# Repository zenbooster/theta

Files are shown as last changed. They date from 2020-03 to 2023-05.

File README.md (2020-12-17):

# "Theta" - EUC Project
Простой, как паровоз, брутальный как бронепоезд ;)

Самодельный корпус для моноколеса.

Watch the video (https://youtu.be/x_wpeCRDHl8)

Для рамы используется экструзионный профиль 2020 и 2040.
Надо сделать сужение кверху.

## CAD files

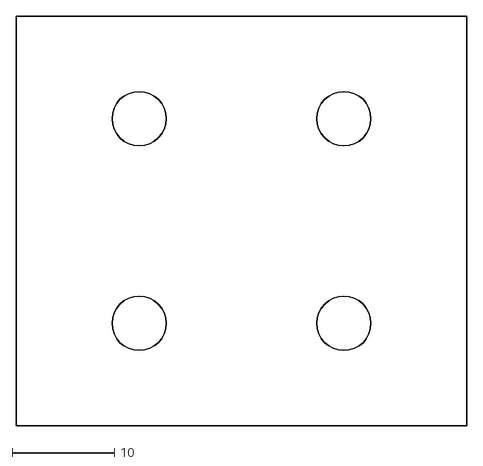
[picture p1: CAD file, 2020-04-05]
vector/dxf/4x_bcb.dxf
44.0 x 40.0

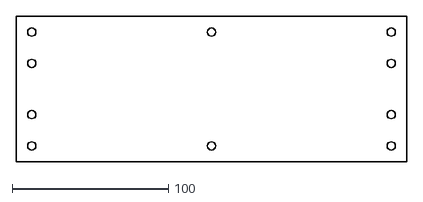
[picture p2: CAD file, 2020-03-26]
vector/ict.dxf
250.0 x 92.8

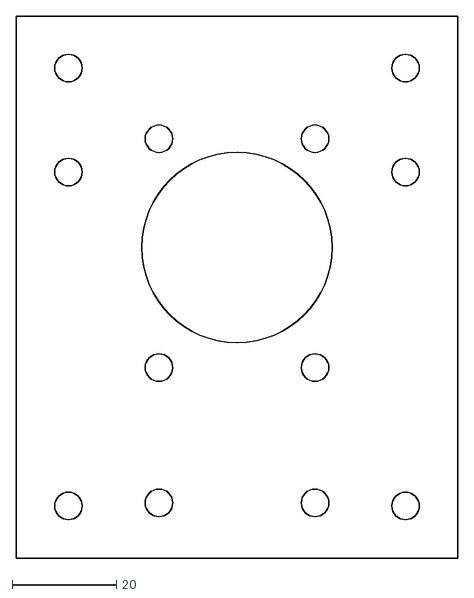
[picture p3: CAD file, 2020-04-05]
vector/dxf/2x_smc.dxf
84.8 x 104.2

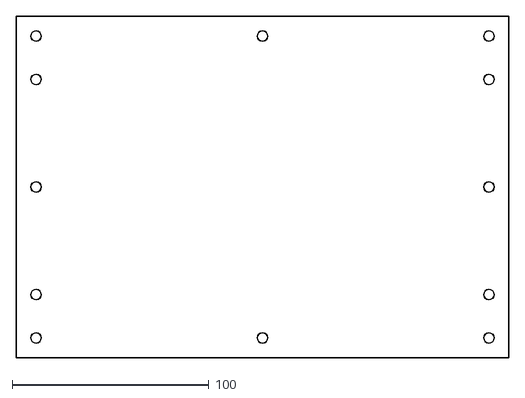
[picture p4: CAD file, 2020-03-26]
vector/icl.dxf
250.0 x 173.3

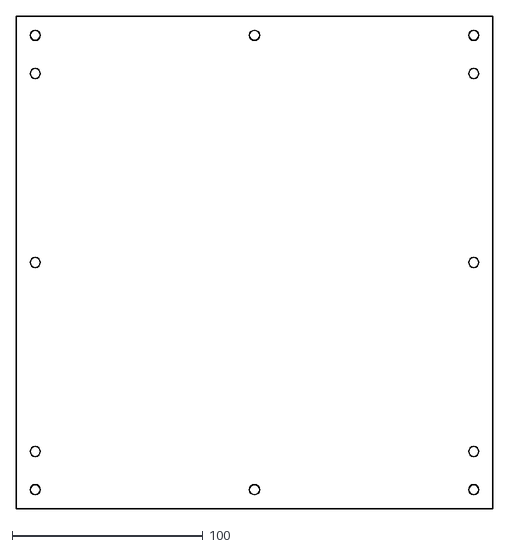
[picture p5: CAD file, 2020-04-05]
vector/dxf/2x_ocs.dxf
250.0 x 258.3

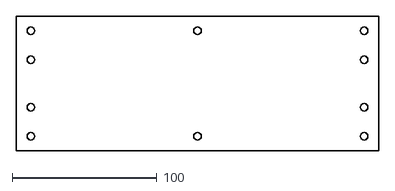
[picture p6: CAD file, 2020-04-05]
vector/dxf/1x_ict.dxf
250.0 x 92.8

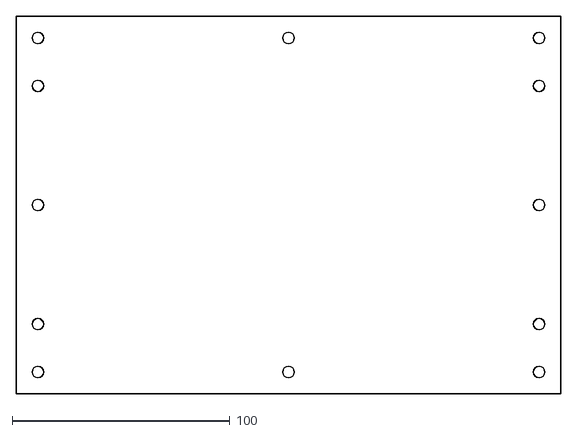
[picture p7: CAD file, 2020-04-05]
vector/dxf/1x_icl.dxf
250.0 x 173.3

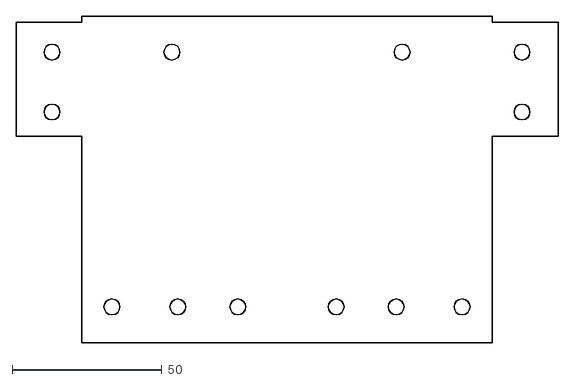
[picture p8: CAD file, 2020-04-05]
vector/dxf/2x_bct.dxf
180.8 x 109.0

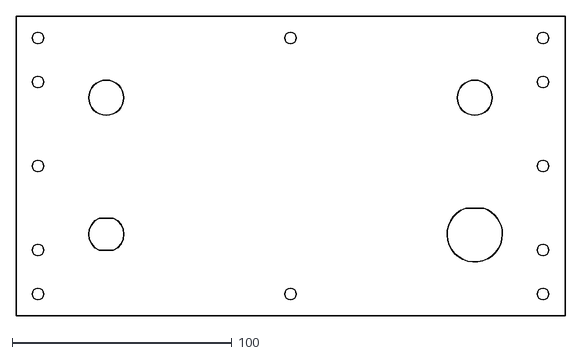
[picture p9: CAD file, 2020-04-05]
vector/dxf/1x_oct.dxf
250.0 x 136.6

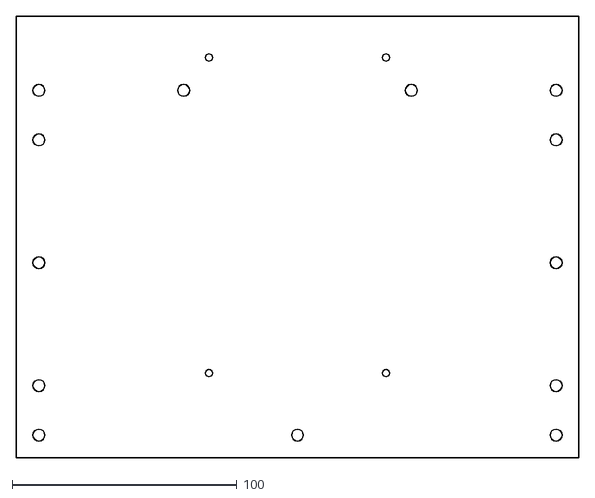
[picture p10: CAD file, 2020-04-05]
vector/dxf/1x_icr.dxf
250.0 x 196.2

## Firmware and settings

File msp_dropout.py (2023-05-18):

#!/usr/bin/env python3
#coding: utf-8
from zencad import *
from common import *
from holes import *
import metric
from sys import exit
from math import sin, cos, asin, tan, sqrt

dropout_width = 45
dropout_height = 136.7
dropout_depth = 23.7
dropout_m_axle_pos = 42.5
dropout_p_axle_pos = 40.2
dropout_sole_size = 51.8
dropout_sole_pos = 88

nut_m5_len = dropout_depth
nut_m5 = metric.metric_nut(5, 0.8, nut_m5_len, False).rotateX(deg(90)).forw(nut_m5_len/2)

small_rounding_r = 4
sole_angle = 2.5
sole_thick = 24
sole_thick_before_rounding_cathet_a = (sole_thick-small_rounding_r) * cos(deg(sole_angle))
small_rounding_cathet_b = small_rounding_r*sin(deg(sole_angle))
delta_after_rounding = small_rounding_r-small_rounding_cathet_b
top_padding_holes = 1 + 5/2
wheel_axle_big_d = 37
wheel_axle_small_d = 16.5
pedal_axis_d = 8
bevel_height = 4.3

def get_dropout_holes(ht):
	while(True):
		if ht == HoleType.tap:
			d = hole_tap_d[5]
			n = cylinder(r=d/2, h=nut_m5_len, center=True).rotateX(deg(90))
		elif ht == HoleType.threaded:
			d = 5
			n = nut_m5
		elif ht == HoleType.fasteners:
			d = hole_d[5]
			n = cylinder(r=d/2, h=nut_m5_len, center=True).rotateX(deg(90))
		else:
			print('ERROR: invalid hole type! HoleType.fasteners will be used.')
			ht = HoleType.fasteners
			continue
		
		break

	hw = 30.6 / 2
	res = n.left(hw) + n.right(hw)
	n = n.down(77.5)
	res += n.left(hw) + n.right(hw)
	n = n.down(35.5)
	res += n.left(hw) + n.right(hw)
	return res

def get_dropout_below_bevel_height():
	return sole_thick_before_rounding_cathet_a+delta_after_rounding

def get_dropout_straight_back_height():
	bbh = get_dropout_below_bevel_height()
	return dropout_height-bbh

def get_dropout_higher_bevel_height():
	sbh = get_dropout_straight_back_height()
	return sbh-(dropout_depth+bevel_height)*tan(deg(sole_angle))

def get_dropout(is_threaded = True):
	sole = box(dropout_width, dropout_sole_size, sole_thick, center=True)
	
	delta = small_rounding_r+0.1
	a = sole_thick - delta
	b = (dropout_sole_size - (dropout_p_axle_pos))/4
	c = sqrt(a*a + b*b)
	step_size = 0.2
	f = a*b/c+step_size
	beta = asin(b/c)
	delta = (c - sole_thick)/2 + delta
	cut = box(dropout_width, f, c, center=True).up(delta)
	cut = cut.translate(0, -f/2, c/2-delta)
	cut = cut.rotateX(-beta)
	cut = cut.translate(0, f/2, -c/2+delta)

	sole -= cut.back((dropout_sole_size+f)/2-step_size)
	sole = sole.translate(0, -dropout_sole_size/2, -sole_thick/2)
	sole = sole.rotateX(deg(-sole_angle))
	sole = sole.translate(0, dropout_sole_size/2, sole_thick_before_rounding_cathet_a/2)
	holes = get_dropout_holes(is_threaded and HoleType.threaded or HoleType.tap).up(dropout_height/2-top_padding_holes)
	bbh = get_dropout_below_bevel_height()
	sbh = get_dropout_straight_back_height()
	res = box(dropout_width, dropout_depth, sbh, center=True).up(bbh/2)
	sole = sole.fillet(r=sole_thick/2, refs=[(0, -dropout_sole_size/2, sole_thick/2)])
	sole = sole.fillet(r=small_rounding_r, refs=[(0, dropout_sole_size/2, -sole_thick/2), (0, -dropout_sole_size/2, -sole_thick/2)])
	res += sole.back((dropout_sole_size-dropout_depth)/2).down((dropout_height-sole_thick_before_rounding_cathet_a)/2 - delta_after_rounding)
	res -= holes
	
	res -= cylinder(r=wheel_axle_small_d/2, h=dropout_depth, center=True).rotateX(deg(90)).up((dropout_height)/2 - dropout_m_axle_pos)
	hblock = 4.5
	hd = hblock+4.9#7.8
	res -= cylinder(r=wheel_axle_big_d/2, h=dropout_depth-hd, center=True).rotateX(deg(90)).up((dropout_height)/2 - dropout_m_axle_pos).back(hd/2)
	a = 8.4
	b = 9.0
	c = 11.8
	block = polygon(pnts=[(-a/2, -c/2), (-a/2, -c/2+b), (a/2, c/2), (a/2, -c/2)], wire=False).extrude(vec=dropout_width, center=True).rotateX(deg(90)).rotateZ(deg(-90)).forw((dropout_depth-a)/2 - hblock)
	s = 7.8
	res -= block.up((dropout_height)/2 - dropout_m_axle_pos + c/2+s/2)
	res -= block.mirrorXY().up((dropout_height)/2 - dropout_m_axle_pos - c/2-s/2)
	hdc = hblock+3
	cut = cylinder(r=wheel_axle_big_d/2, h=dropout_depth-hdc, center=True).rotateX(deg(90))
	cut ^= box(wheel_axle_big_d, dropout_depth-hdc, s, center = True)
	cut = cut.up((dropout_height)/2 - dropout_m_axle_pos).back(hdc/2)
	res -= cut
	
	ph = 18
	L = (dropout_height)/2-52.5
	pw = 8
	cut = box(dropout_width, pw, ph, center=True)
	cut = cut.fillet(r = pw/2.01, refs=[(0, 1, ph/2), (0, -1, ph/2), (0, 1, -ph/2), (0, -1, -ph/2)])
	#res -= cut.up(L-ph/2).back(-dropout_depth/2-pw/2+a+hblock)
	
	L -= ph+8
	
	ph = 15
	cut = box(dropout_width, pw, ph, center=True)
	cut = cut.fillet(r = pw/2.01, refs=[(0, 1, ph/2), (0, -1, ph/2), (0, 1, -ph/2), (0, -1, -ph/2)])
	#res -= cut.up(L-ph/2).back(-dropout_depth/2-pw/2+a+hblock)
	
	L -= ph+4

	ph = 24
	cut = box(dropout_width, ph, pw, center=True)
	cut = cut.fillet(r = pw/2.01, refs=[(0, ph/2, 1), (0, ph/2, -1), (0, -ph/2, 1), (0, -ph/2, -1)])
	#res -= cut.up(L-pw/2).back(-dropout_depth/2-pw+a+hblock + ph/2)
	
	res -= cylinder(r=gap(pedal_axis_d, 2)/2, h=dropout_width, center=True).rotateY(deg(90)).up(L).back(dropout_p_axle_pos - dropout_depth/2)
	
	#усиление угла:
	a = sqrt(2*(4.3**2))
	hbh = get_dropout_higher_bevel_height()
	res += box(dropout_width, a, a, center=True).rotateX(deg(45)).back(dropout_depth/2).down(-dropout_height/2 + hbh)
	
	#res += box(dropout_width, dropout_depth, dropout_height, center=True).forw(dropout_depth*2)
	#res += box(dropout_width, dropout_depth, dropout_height, center=True).rotateX(deg(90)).down((dropout_height+dropout_depth)/2)
	return res

if __name__ == "__main__":
	is_3d_print = False
	m = get_dropout(not is_3d_print)
	if is_3d_print:
		#to_stl(m, 'd:\mcm5dropout.stl', 0.01)
		'''
		bbh = get_dropout_below_bevel_height()
		sbh = get_dropout_straight_back_height()
		h = top_padding_holes + 44 + top_padding_holes
		to_stl(m ^ box(dropout_width, dropout_depth, h, center=True).up(dropout_height/2 - h/2), 'd:\mcm5dropout_top.stl', 0.01)
		'''
		'''
		sy = dropout_sole_size + 1
		sz = sole_thick+6
		to_stl(m ^ box(dropout_width, sy, sz, center=True).down(dropout_height/2 - sz/2).back((sy-dropout_depth)/2), 'd:\mcm5dropout_bottom.stl', 0.01)
		'''
		pass

	display(m)#, color=(1, 1, 1, 0.5))
	show()

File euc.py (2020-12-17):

#!/usr/bin/env python3
#coding: utf-8

import sys
from math import sqrt, tan, ceil
import metric
from common import *
from shell import *
from mcm5v2dropout import *
#from mcm5dropout import *
import usb

#alp2020l = from_brep('./brep/alp2020l.brep')
alp2020l = from_brep('./brep/alp2020almk.brep').left(47.4).back(75.2)
#alp2040l = from_brep('./brep/alp2040l.brep').left(10)
alp2040l = from_brep('./brep/alp2040almk.brep').back(81.55).left(37.25)
#alp2040l = from_brep('./brep/alp2040almk.brep').back(81.5404).left(37.25)
alp4040con = from_brep('./brep/alp4040con.brep').scaleZ(0.1)
con2020d = from_brep('./brep/con2020d.brep')
con2020 = from_brep('./brep/con2020.brep').left(10).down(6.25).rotateY(deg(-90)).rotateX(deg(180))
con2040 = from_brep('./brep/con2040d.brep').right(38.1/2).back(38.1/2).down(17.4/2)#.rotateZ(deg(-90))
con2040s = from_brep('./brep/con2040s.brep').down(18/2 - 2).left(38.5/2).back(38.5/2).rotateX(deg(90)).rotateY(deg(180))
con4040s = from_brep('./brep/con4040s.brep').down((38.5-3.7)/2).rotateX(deg(90)).left(38.5/2).down(38.5/2)
gx16 = from_brep('./brep/GX16-4.brep').rotateX(deg(90)).rotateZ(deg(90))
power_button = from_brep('./brep/PV2F640xx.brep').rotateX(deg(90)).down(12)
handle = from_brep('./brep/handle108mm.brep').rotateX(deg(90))

gap_dropout_width = gap(dropout_width, 2)
gap_dropout_height = gap(dropout_height)
gap_dropout_depth = gap(dropout_depth)
gap_dropout_sole_pos = gap(dropout_sole_pos)

ddt = gap_dropout_depth - 20
dcdt = ddt - cover_thickness

len2020v = (gap_dropout_sole_pos - 4)
len2020h_rib = wheel_arch_width - 40 + dcdt*2# - cover_thickness*2
len2020h_rib2 = wheel_arch_width + ddt*2
len2020_guid = side_compartment_width
len2020_drw = dropout_width + 20*2

h_rib += dropout_m_axle_pos
h_rib2 = 10+dropout_m_axle_pos + side_compartment_height
h_icl = h_rib - dropout_m_axle_pos + 10 - 20
h_icr = 20 + common_clearance + ctrl_height
h_icr += 8 - (h_icr-h_icl-18.3)*2 # 8 - размер опорной поверхности под М3.

dmns_shell_mount_cover = (dropout_width + 20*2, cover_thickness, len2020v + 20)

def display_shell(alpha):
    mv = get_alp2040(side_compartment_height - 20*2 - 40).rotateZ(deg(90))
    mh = get_alp2040(side_compartment_width - 20).rotateZ(deg(90)).rotateY(deg(90)).down(side_compartment_height/2 - 10).right(10)
    #m = mv.left(side_compartment_width/2 - 10).down(40/2)
    #m = mv.right(side_compartment_width/2 - 10).down(40/2)
    m = mv.left(side_compartment_width/2 - 10 - 20).down(40/2)
    m += mv.left(side_compartment_width/2 - 10).down(40/2).mirrorYZ()
    #m += m.mirrorYZ()
    m += mh
    
    #m += get_alp2040(side_compartment_width).rotateY(deg(90)).rotateX(deg(90)).up(side_compartment_height/2 - 50)
    #m += get_alp2040(side_compartment_width).rotateY(deg(90)).forw(10).up(side_compartment_height/2 - 20)

    m += get_alp2040(side_compartment_width - 20).rotateY(deg(90)).rotateX(deg(90)).up(side_compartment_height/2 - 50).right(10)
    #t = get_alp2040(side_compartment_width).rotateY(deg(90))
    #t -= box(20, center=True).up(10).left(side_compartment_width/2 - 10)
    #m += t.forw(10).up(side_compartment_height/2 - 20)
    t = get_alp2020(side_compartment_width).rotateY(deg(90))
    m += t.forw(10).up(side_compartment_height/2 - 30)
    t = get_alp2020(side_compartment_width - 20).rotateY(deg(90))
    m += t.forw(10).up(side_compartment_height/2 - 10).right(10)

    #m += get_alp2040(side_compartment_height - 40).rotateX(deg(90)).left(side_compartment_width/2 - 50).down(20)
    #m += get_alp2040(side_compartment_height - 40).forw(10).left(side_compartment_width/2 - 20).down(20)
    m += get_alp2020(side_compartment_height - 40).forw(10).left(side_compartment_width/2 - 10).down(20)
    
    m = m.up(side_compartment_height/2 + dropout_m_axle_pos + 20)
    m = m.back(wheel_arch_width/2 + 20 + ddt)
    m += m.mirrorXZ()

    # нижние и верхние поперечные балки верхнего отсека:
    htop = len2020h_rib
    rib = get_alp2020(htop).rotateX(deg(90)).up(h_rib)
    rib = rib.left(side_compartment_width/2 - 10)
    rib += rib.mirrorYZ()

    rib2t = get_alp2040(len2020h_rib2).rotateX(deg(90)).rotateY(deg(90)).up(h_rib2-10)
    rib2t = rib2t.right(side_compartment_width/2 - 10)
    
    rib2h = get_alp4040con(len2020h_rib2).rotateX(deg(90)).mirrorYZ().up(h_rib2 - 20)
    rib2h = rib2h.left(side_compartment_width/2 - 10-20)

    m += rib + rib2h + rib2t

    guide = get_alp2020(len2020_guid).rotateY(deg(90))
    guide = guide.up(h_rib)
    guide = guide.back(wheel_arch_width/2 - 10 + dcdt)
    guide += guide.mirrorXZ()
    m += guide

    # уголки усиливающие нижнюю часть верхнего отсека:
    con = con2020d.rotateY(deg(90)).up(h_rib).left(side_compartment_inner_width/2 - 18/2).back(wheel_arch_width/2 - 20 - 18/2 + dcdt)
    con += con.mirrorXZ()
    con += con.mirrorYZ()
    m += con
    
    # уголки усиливающие торцевые части верхнего отсека:
    #con = con2020.rotateX(deg(90)).up(h_rib2-10-20).left(side_compartment_width/2 - 20/2).back(wheel_arch_width/2 - 20/2 + ddt)
    con = con2040.rotateY(deg(90)).up(h_rib2-10-40).left(side_compartment_width/2 - 20/2).back(wheel_arch_width/2 - 40/2 + ddt)
    con += con.mirrorXZ()
    con += con.mirrorYZ()
    m += con

    # внутренняя верхняя крышка
    hitc = htop + 20*2
    inner_cover = box(side_compartment_width, hitc, cover_thickness, center = True)
    hole = cylinder(hole_d[5]/2, cover_thickness, True)
    holes = hole.forw(hitc/2 - 10).left(side_compartment_width/2 - 10)
    holes += holes.mirrorYZ()
    holes += hole.forw(hitc/2 - 10)
    holes += holes.mirrorXZ()
    holes2 = hole.forw(hitc/2-10-20).left(side_compartment_width/2 - 10)
    holes2 += holes2.mirrorYZ()
    holes2 += holes2.mirrorXZ()
    holes += holes2
    inner_cover -= holes
    #to_brep(inner_cover, "vector/1x_ict.brep")
    inner_cover = inner_cover.up(h_rib - 10 - cover_thickness/2)
    m += inner_cover
    
    # внутренние боковые крышки
    icl = box(side_compartment_width, h_icl, cover_thickness, center = True).rotateX(deg(90))
    hole = cylinder(hole_d[5]/2, cover_thickness, True).rotateX(deg(90))
    holes = hole.up(h_icl/2 - 10).left(side_compartment_width/2 - 10)
    holes += holes.mirrorYZ()
    holes += holes.down(20 + cover_thickness)
    holes += holes.mirrorXY()
    holes += holes + hole.down(h_icl/2 - 10)
    holes += hole.left(side_compartment_width/2 - 10) + hole.right(side_compartment_width/2 - 10)
    t = hole.up(h_icl/2 - 10)
    holes_l = holes + t
    t = t.left(ctrl_width/2 + gap(11.8/2)) # 11.8 - самый большой диаметр шляпки винта М5, что удалось на вскидку найти...
    holes_r = holes + t + t.mirrorYZ()

    icl -= holes_l
    #to_brep(icl.rotateX(deg(90)), "vector/1x_icl.brep")
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

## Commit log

2019-11-28 спользуются трубчатые шпильки выполняющие роль одновременно шпангоутов и кабельных вводов.
2019-11-28 Избавился от трубчатых шпангоутов. Добавил панель управления.
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2019-11-29 Простой, как паровоз, брутальный, как бронепоезд ;)
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2019-11-29 Заменил ручку. Отцентровал получше коробку. Рефакторинг.
2019-11-29 Удалил лишнюю модель, дополнил readme.
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2019-11-29 отверстия под крепления к стойкам в боковых отсеках
2019-11-29 Поправил inner_spacer; сделал кондуктор get_shell_mount_holes().
2019-11-29 get_sm_spacer() теперь использует кондуктор get_shell_mount_holes()
2019-11-29 Добавил отверстия для крепления верхнего отсека к нижним.
2019-12-02 Добавил верхние внутренние шайбы. Поправил нижние внутренние шайбы.
2019-12-08 стойка GW MCM5 на стадии допиливания
2019-12-08 Верхние отверстия смещены к углам, шайбы теперь опираются на 2 стороны.
2019-12-09 gwdropout.py: теперь высота стойки соответствует измеренному значению, с учётом закругления.
2019-12-09 gwdropout.py: вынес некоторые константы.
2019-12-09 gwdropout.py: улучшена форма носка.
2019-12-09 gwdropout.py: ещё улучшил форму носка.
2019-12-10 euc.py: прикрутил стойки от mcm5
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2019-12-12 Усилил крепления к стойкам. Подвинул отверстия крепления корпуса, что бы головки болтов влезли перед дном боковых отсеков и могли крутиться. Гайки при этом окажутся зажатыми между рёбер жёсткости. Ре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
2019-12-13 Пляски вокруг кабеля мотора.
2019-12-17 Подвинул отверстие под разъём вму-20, для того, чтоб был запас по радиусу кривизны металлорукава. (ВМУ-20 был поставлен в прошлом коммите взамен PG-29.)
2019-12-18 Добавил усиление угла в стойку. Укоротил крепление к стойкам.
2019-12-19 Добавил перечисление HoleType. mcm5dropout.get_dropout_holes теперь умеет делать отверстия под нарезание резьбы. в mcm5dropout добавил возможность сохранения stl моделей отдельных частей стойки для 3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
2019-12-20 Для линукса поправил имя файла с корпусом.
2019-12-20 Продольные дуги теперь соединены друг с другом.
2019-12-23 common.py: перемерял side_compartment_depth euc.py: добавил поперечные дуги
2019-12-23 Добавил иллюстрацию в readme.md.
2019-12-23 Удалил модель со старой ручкой.
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2019-12-24 Ещё подвинул крепления дуг.
2020-03-18 Поменял расположение отверстий для крепления верхнего отсека. Заменил кабельный ввод на МВН-НС-М20-МР20. Добавил отверстия под кабель из боковых отсеков в верхний.
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2020-03-21 доработка рамы + внутренние крышки
2020-03-23 Доделал раму. Начал расчет необходимого количества материалов.
2020-03-23 исправил опечатку
2020-03-23 еще один баг поправил
2020-03-23 Примерил батареи, скорректировал размеры. Длина корпуса теперь равна длине зауженых хексов: 250 мм.
2020-03-24 Заменил поставщика профиля 2020 с "соберизавод" на "alumica.ru".
2020-03-24 добавил крышки для шелмаунтов
2020-03-24 еще немного отверстий в крышки шелмаунтов...
2020-03-24 досверлил отверстия в крышках шелмаунтов
2020-03-24 заменил уголки у шелмаунтов
2020-03-24 Рефакторинг. Докинул модель con2040s.
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2020-03-24 заменил поставщика профиля 2040 на alumica.ru
2020-03-25 поправил диаметр отверстий в крышках шелмаунтов
    [smcov.stl]
2020-03-25 добавил отверстия для крепления к раме во внутренних боковых крышках
2020-03-25 вернул правую внутреннюю крышку, добавил контроллер
2020-03-25 увеличил высоту правой внутренней крышки, чтобы радиатор контроллера контактировал с ней по всей площади
2020-03-25 исправил косяк с размером в ddt и len2020h_rib
    [euc.py]
2020-03-26 добавил отверстий во внутреннюю верхнюю крышку
    [smcov.dxf]
2020-03-26 в правой внутренней крышке вынес отверстие из под контроллера в два отверстия побокам
    [icl.dxf, smcov.stl]
2020-03-26 добавил dxf для верхней внутренней крышки
    [ict.dxf]
2020-03-26 добавил внешние боковые крышки
2020-03-26 добавил верхнюю внешнюю крышку
2020-03-27 добавил отверстий в верхнюю внешнюю крышку
2020-03-27 заготовка для торцевых крышек
2020-03-27 добавил верхние торцевые крышки без отверстий
2020-03-27 добавил отверстий в торцевые крышки
2020-03-30 сделал отверстия для крепления контроллера GW MCM5 84V
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2020-04-03 добавил уголки с торцов верхнего кронштейна
2020-04-03 в верхней части верхнего отсека поменял расположение уголков, чтоб не мешали разъёмам
2020-04-03 вернул крышки на место
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2020-04-05 добавил векторные файлы для резки
    [1x_icl.dxf, 1x_icr.dxf, 1x_ict.dxf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]
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2020-10-23 Вместо угловой балки разместил 2 балки 20х40. Поправил верхние торцевые крышки.
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2020-10-26 Поменял стойки на mcm5v2 (ось педалей стала ближе к оси мотора). Поставил покрышку 14x3.0 (по факту, 16 дюймов). Заморозил старые размеры покрышки и положение оси мотора относительно стоек, что бы св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
2020-10-26 Поправил баги: добавил замороженную версию для dropout_m_axle_pos с префиксом shell_. Исправил размер покрышки.
    [euc.py, shell.py]
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2020-10-29 Уменьшил ширину колёсной арки на 1 мм, т.к. в реальной конструкции после затягивания всех винтов шелмаунты сходятся под небольшим углом. Поправил баг с положением корпуса относительно шелмаунтов, ког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
2020-12-16 Доделал ступеньки под скругления, укоротил верхнюю крышку и балку с ручкой.
2020-12-17 Задняя верхняя балка верхнего отсека (ВО) заменена на 2040. Верхние уголки ВО заменены на 2040. Толщина листов заменена на 1.5 мм.
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
